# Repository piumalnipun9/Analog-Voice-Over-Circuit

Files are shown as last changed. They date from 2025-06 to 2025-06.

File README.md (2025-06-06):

# **Analog Voice-Over Circuit with Channel Prioritization**

This project demonstrates a fully analog implementation of a **Voice-Over Circuit** that effectively handles **two audio channels**, with automatic prioritization of the active channel.

## **Key Features**

- **Channel Prioritization**  
  Automatically prioritizes one channel when an input is detected, ensuring the most important channel is always heard.

- **Independent Volume Control**  
  Allows separate volume adjustments for both channels to tailor the audio output to specific needs.

- **Detection Threshold**  
  Adjustable detection threshold to ensure precise activation based on audio intensity.

- **Purely Analog Design**  
  Developed entirely using basic analog components and ICs, without digital processors, ensuring high-fidelity signal processing.

## **Functionality**

### 🔰 **Band-Pass Filter**  
The journey begins with a **band-pass filter**, which effectively improves the audio signal by reducing unwanted feedback and filtering out high-frequency noise. This step ensures that only the desired frequency range passes through for further processing.

### 🔰 **Pre-Amplifier**  
The filtered signal is then fed to a **pre-amplifier**, which boosts the signal to a level suitable for detection by the subsequent **peak detector circuit**. This ensures that the signal strength is sufficient for accurate analysis.

### 🔰 **Peak Detector Circuit**  
The **peak detector** captures the maximum amplitude of the audio signal, providing a stable DC output that is proportional to the peak amplitude. This step ensures that the highest level of the signal is preserved for accurate evaluation.

### 🔰 **Comparator Circuit**  
Next, the output from the peak detector is evaluated by a **comparator**. The comparator compares the peak value against a **predetermined threshold** and produces a high output when the signal surpasses this threshold. This decision determines whether audio from one channel or another should be activated.

### 🔰 **Control Signal for Switching**  
The **comparator's output** serves as a control signal to efficiently switch between the microphone input and the audio input. The priority channel is selected based on the detection of audio input.

### 🔰 **Main Amplifier**  
The final step involves the **main amplifier**, which amplifies the selected audio signal to a level that can be clearly heard through the **speaker**. The amplification ensures the output is loud and clear.

---

## **What We Learn From This Project**

- **Analog Signal Processing**  
  We gain hands-on experience in designing and implementing various analog circuits such as filters, amplifiers, and detectors. This emphasizes the importance of analog signal conditioning in real-world applications.

- **Audio Channel Management**  
  We learn how to handle multiple audio channels, manage input priorities, and ensure a seamless transition between them based on real-time detection, a valuable skill in audio systems and communication devices.

- **Threshold Detection and Signal Control**  
  This project teaches us how to use **thresholds** for activating or switching channels based on audio signals, a technique used in various applications like voice-activated systems and automatic switching systems.

- **Practical Circuit Integration**  
  Integrating multiple analog components—filters, amplifiers, detectors, comparators—into a cohesive working system gives us insight into how different analog devices can work together to form a complex functional unit.

---

## **Visuals of the Project**

<div style="display: flex; gap: 15px; justify-content: center; flex-wrap: wrap;">

  <!-- PCB -->
  <div style="text-align: center;">
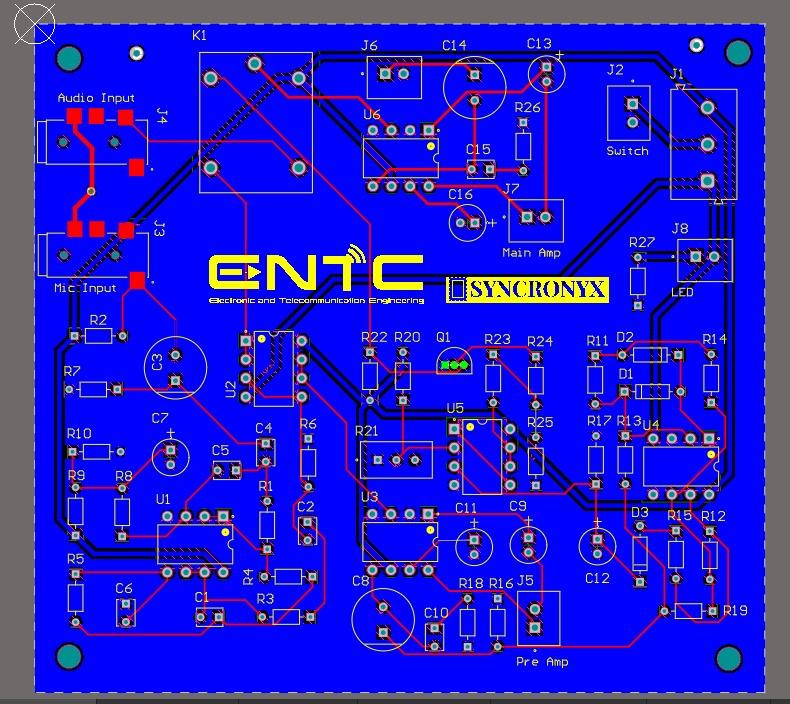
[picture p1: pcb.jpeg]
    
    <div>PCB Design</div>
  </div>

  <!-- Product Image 1 -->
  <div style="text-align: center;">
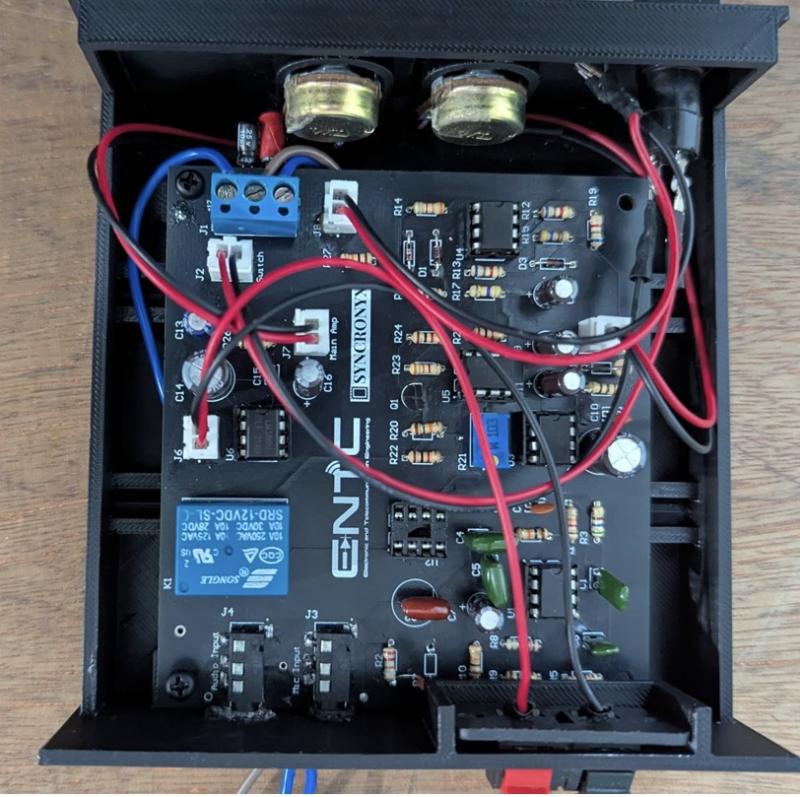
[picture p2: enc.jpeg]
    
    <div>Product Image (Front View)</div>
  </div>

  <!-- Product Image 2 + 3 combined -->
  <div style="text-align: center;">
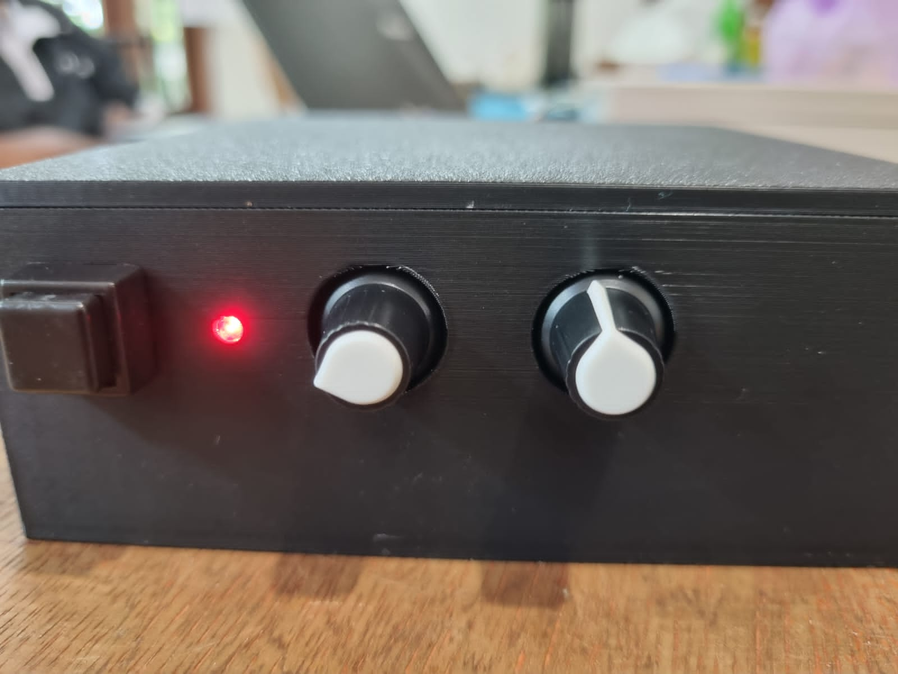
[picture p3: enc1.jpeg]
    
    
    <div>Product Images (Side & Rear Views)</div>
  </div>

</div>

<br/>

<!-- Signal Flow Diagram -->
<div style="text-align: center; margin-top: 30px;">
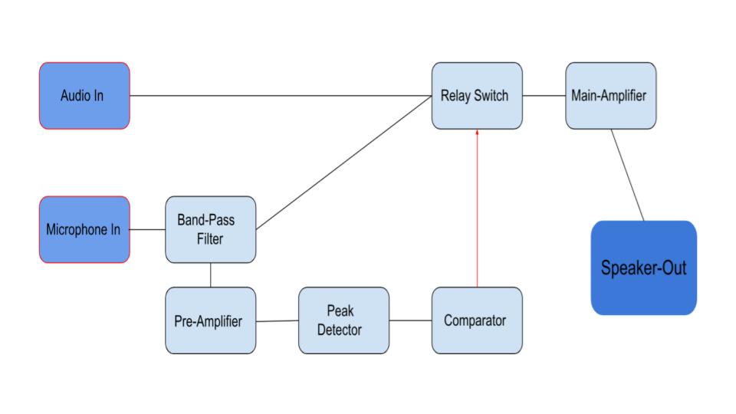
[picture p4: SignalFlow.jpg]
  
  <div>Signal Flow Diagram</div>
</div>

---
Video Demo
## **Components Used:**
- Band-pass filter
- Pre-amplifier IC
- Peak detector circuit
- Comparator IC
- Main amplifier IC
- Various passive components (resistors, capacitors)
## **Specific ICs Used:**
- LM386 for amplifier circuits
- NE5532 for other circuits
---

By completing this project, we develop a deeper understanding of analog systems, gain skills in circuit design and troubleshooting, and enhance our ability to create complex systems using only analog components.

Feel free to fork this repository and contribute to further improvements or modifications!

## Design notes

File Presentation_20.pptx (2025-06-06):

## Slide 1

Audio Voice Over Circuit

The audio voice-over circuit is designed to effortlessly alternate between two audio sources, typically a microphone input and an external audio input, based on user desire. It guarantees higher sound quality with minimum noise, distortion, and latency.

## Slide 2

Audio Voice Over Circuit

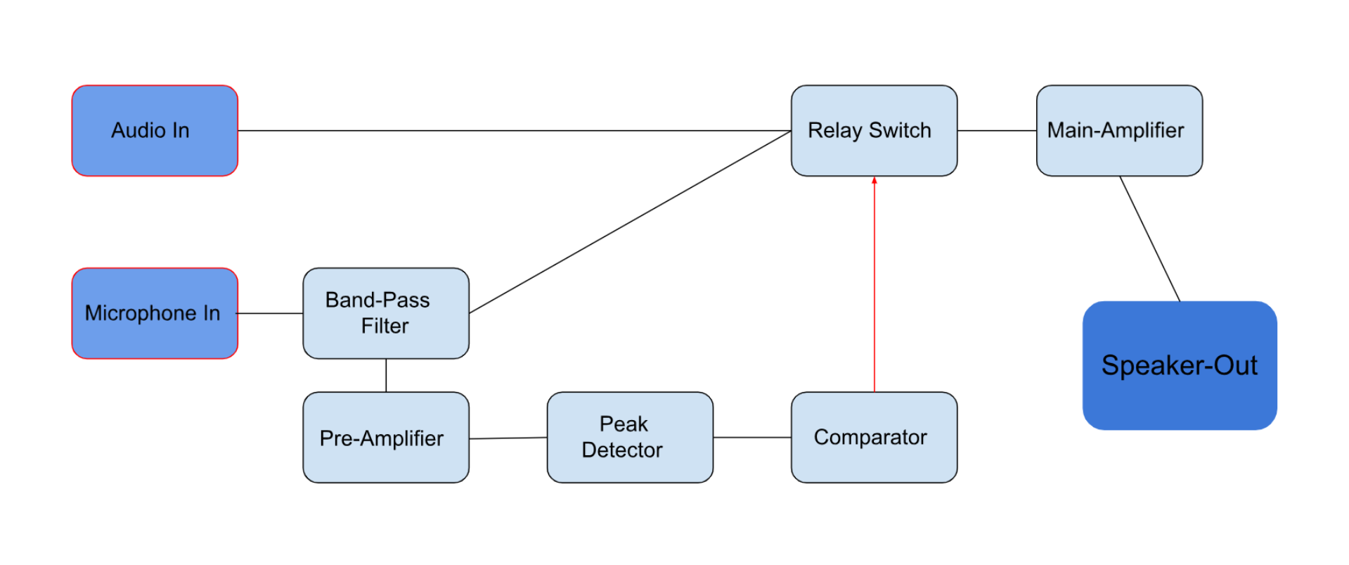
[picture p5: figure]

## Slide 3

Bandpass-Filter

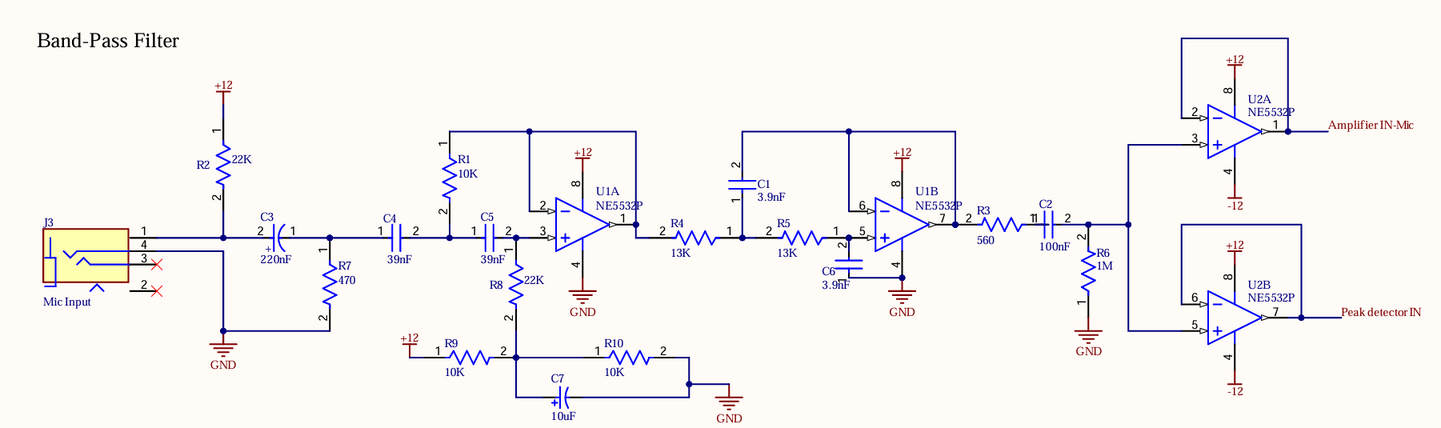
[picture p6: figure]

  - Used NE5532P IC containing two op-amps to build a bandpass filter.
  - Designed to reduce echo feedback from the microphone input.
  - Filter isolates the frequency range of 500-5000 Hz.
  - Ensures clear audio output by minimizing unwanted feedback and preserving signal quality.

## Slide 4

Pre-Amplifier

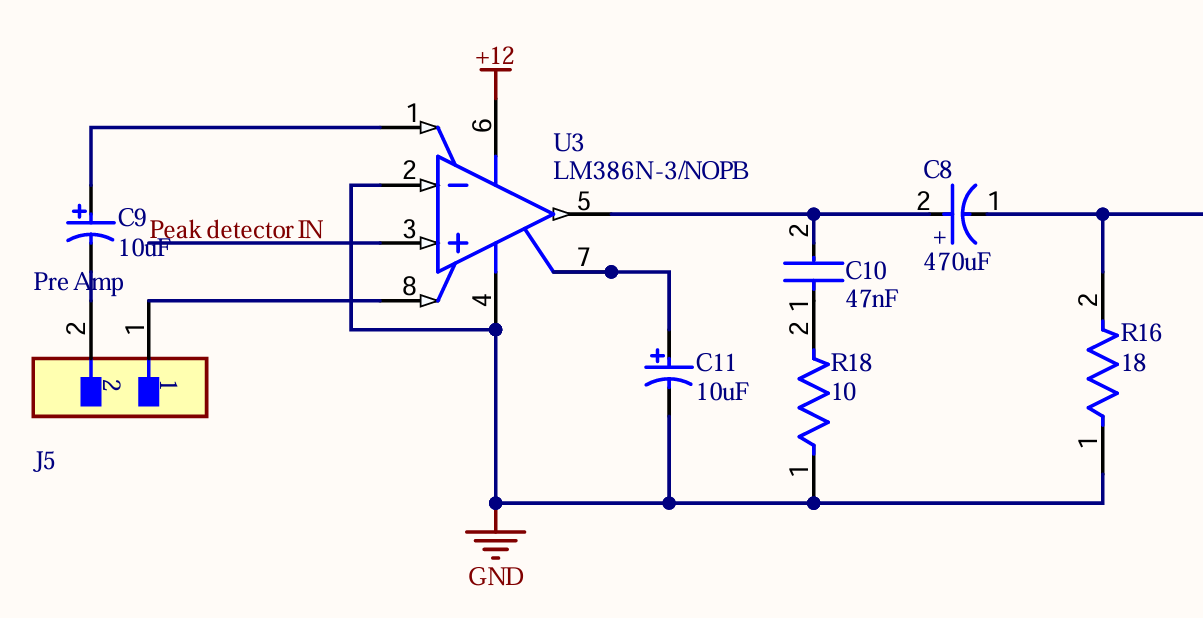
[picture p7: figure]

  - Band-Pass filter output drives through a pre-amplifier.

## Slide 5

Peak-Detector

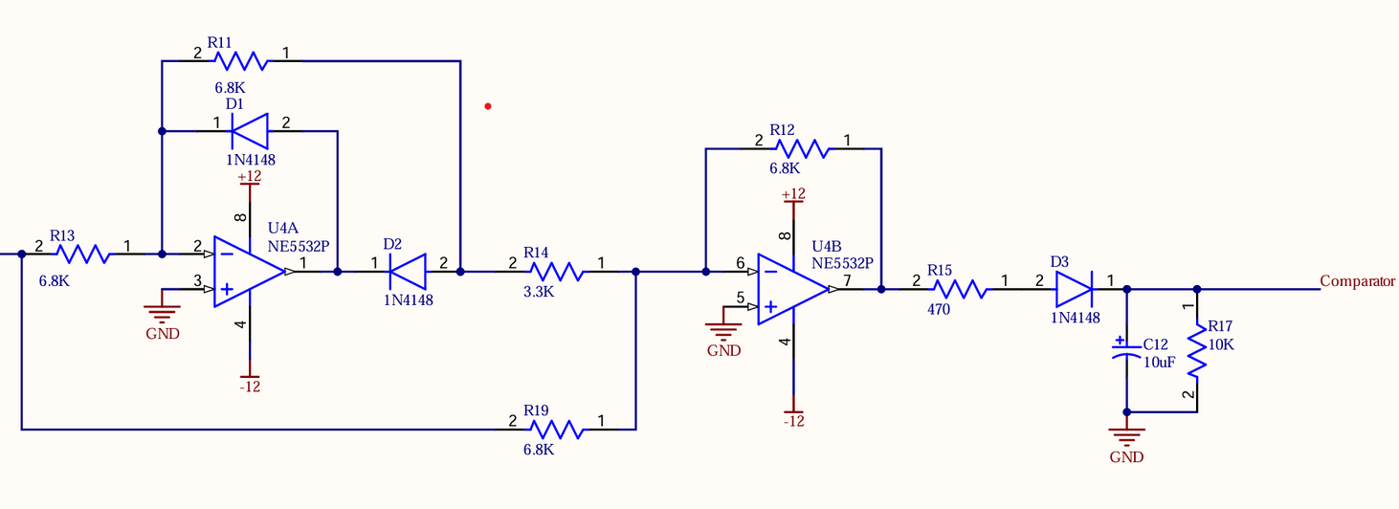
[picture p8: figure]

  - Utilized a NE5532P IC.
  - Circuit captures the peak amplitude of the input audio signal.
  - Provides a steady DC output proportional to the peak amplitude.
  - Output serves as the input to the comparator for threshold detection.

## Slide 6

Comparator

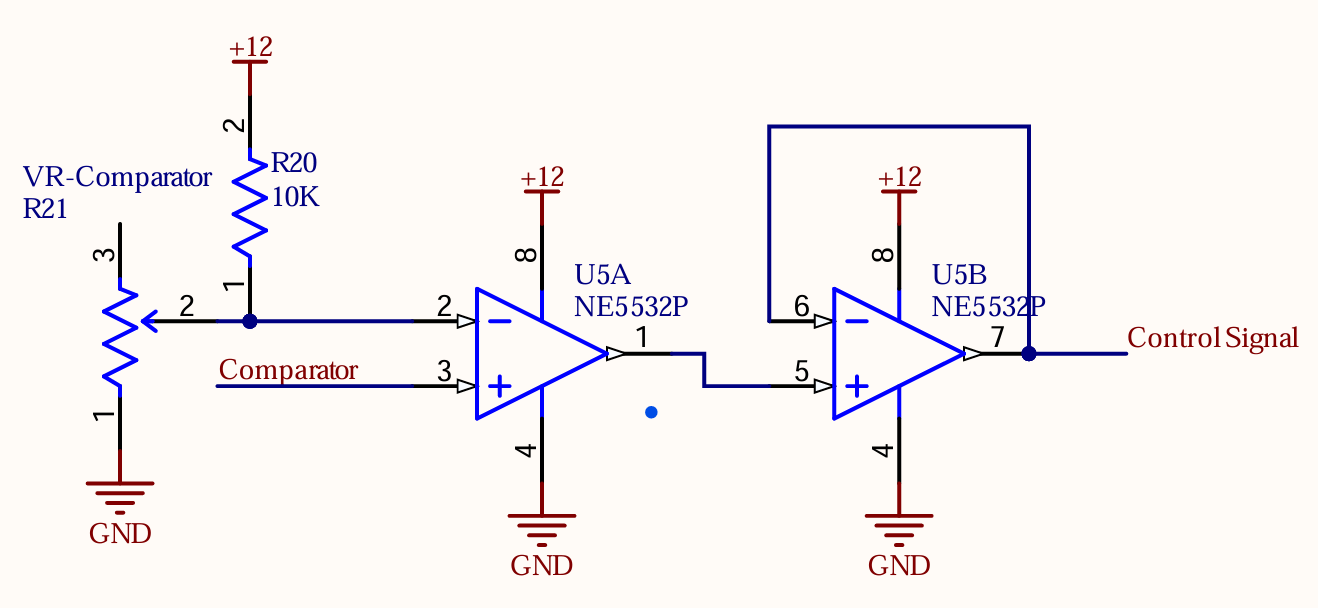
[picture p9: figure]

  - Used another NE5532P IC.
  - Comparator compares the peak detector’s output with a predefined threshold voltage.
  - Generates a high output when the peak signal exceeds the threshold.

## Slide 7

Switching-Circuit

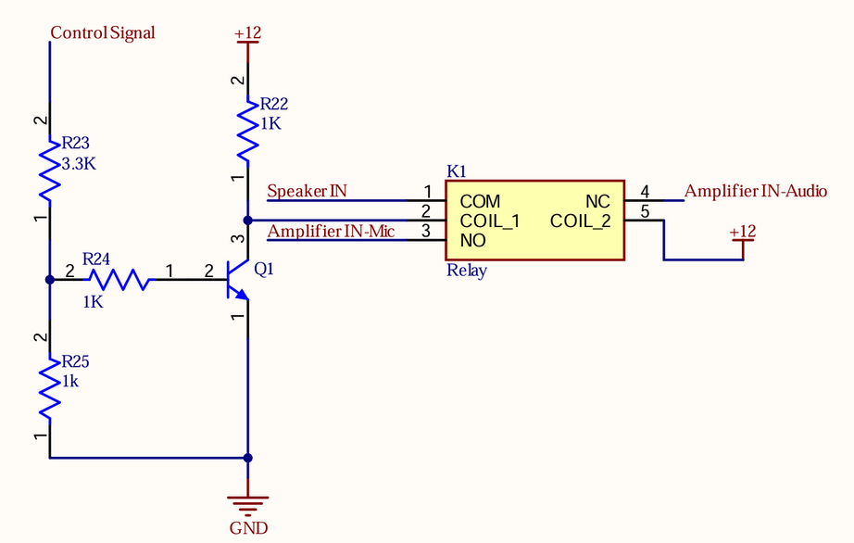
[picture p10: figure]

  - Employed a 2N3904 NPN transistor and a relay.
  - Comparator's output acts as the control signal for the circuit.
  - Transistor output drives the relay.
  - Ensures efficient signal routing between,
  1. microphone input
  2. audio input.

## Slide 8

Main-Amplifier

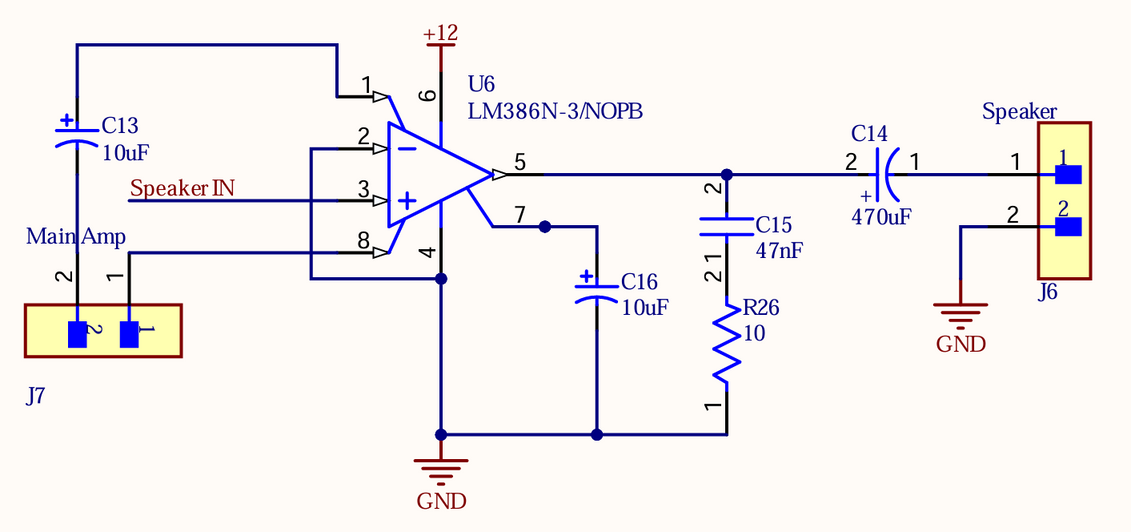
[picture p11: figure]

  - Used the LM386N IC to build an audio amplifier.
  - Designed to boost the signal strength for audio applications.
  - Provides sufficient gain and output power for clear sound.
  - Amplifies the input audio signal effectively.
  - Ensures compactness and energy efficiency in the overall design.

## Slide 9

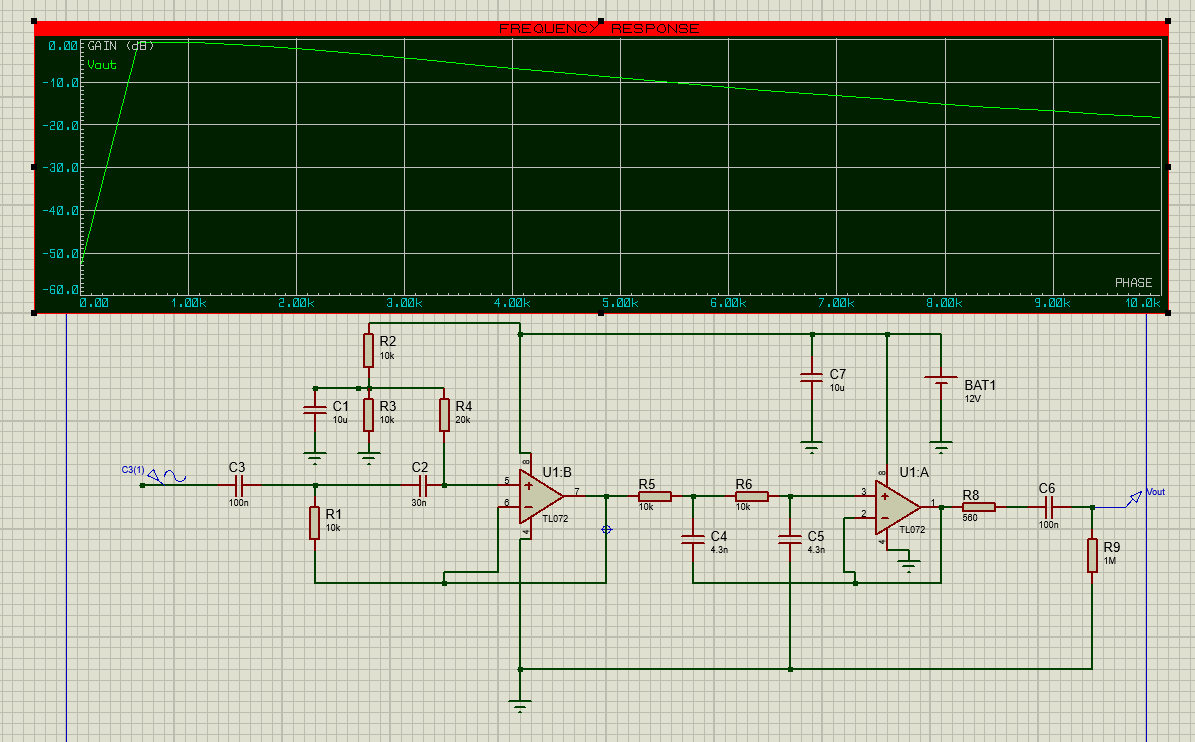
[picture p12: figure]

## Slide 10

PCB Design

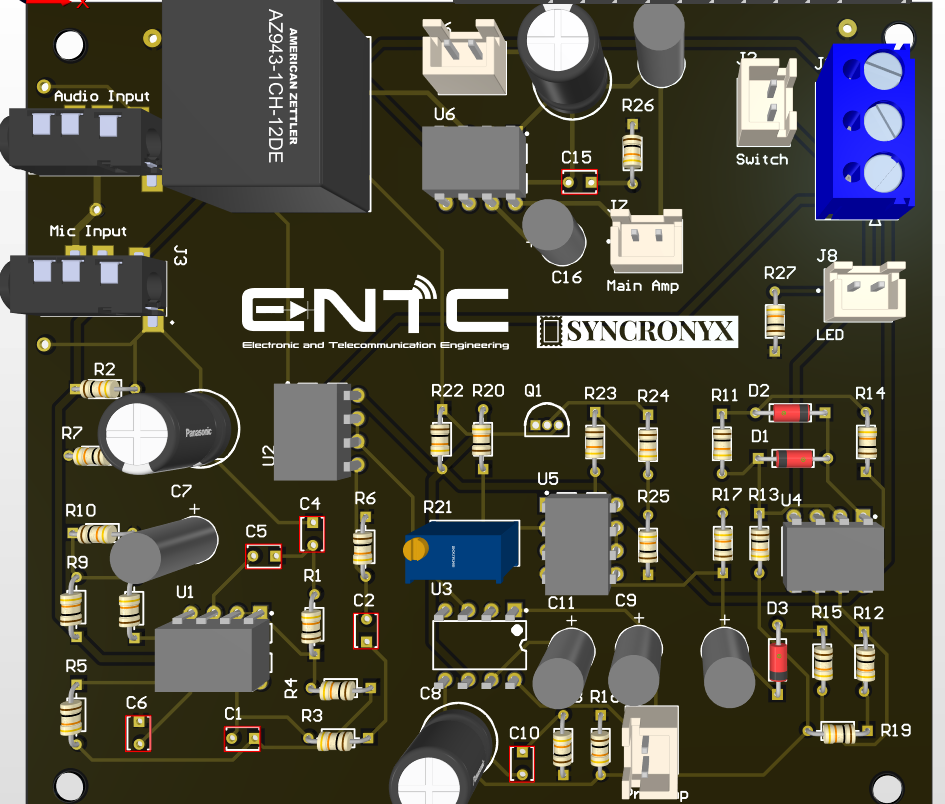
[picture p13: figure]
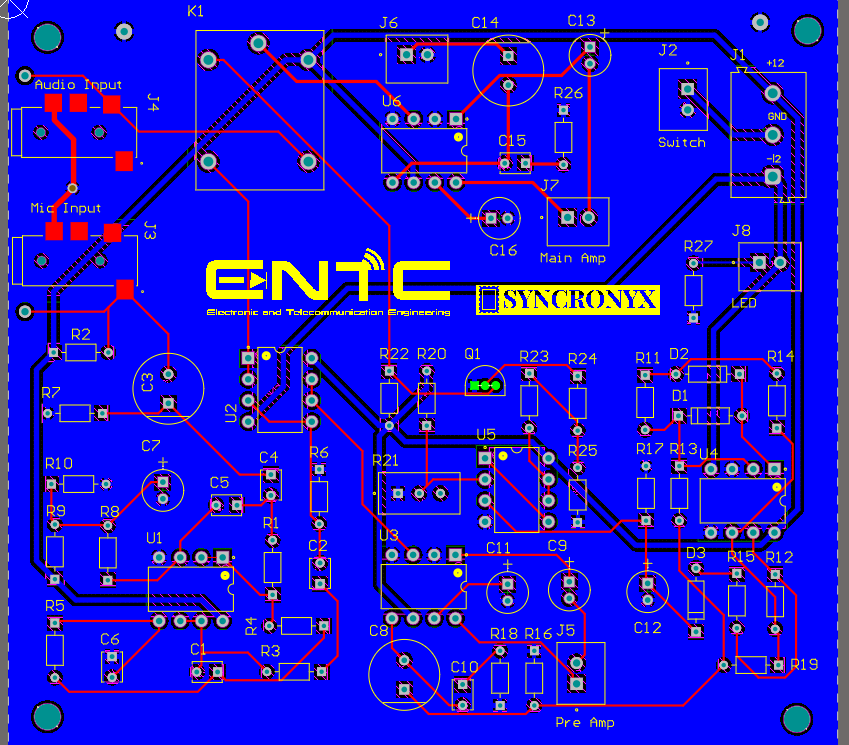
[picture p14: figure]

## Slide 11

Enclosure

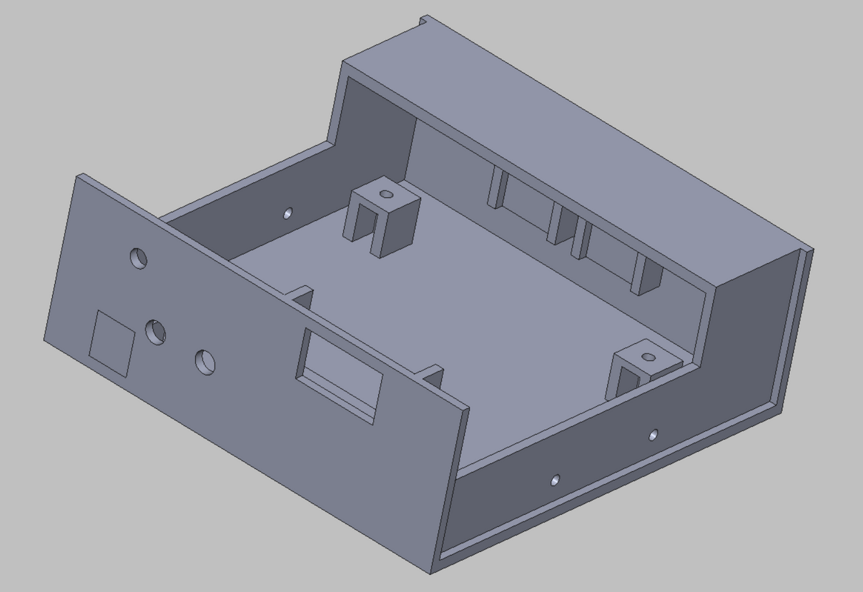
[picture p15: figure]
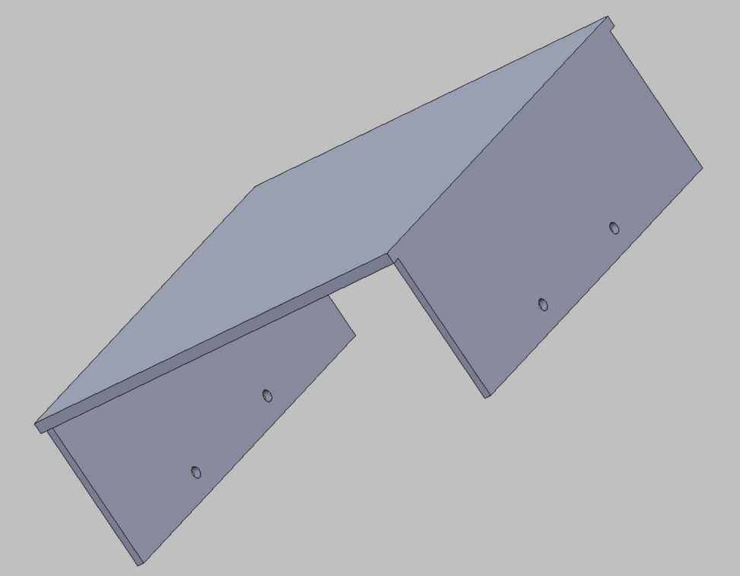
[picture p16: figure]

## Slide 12

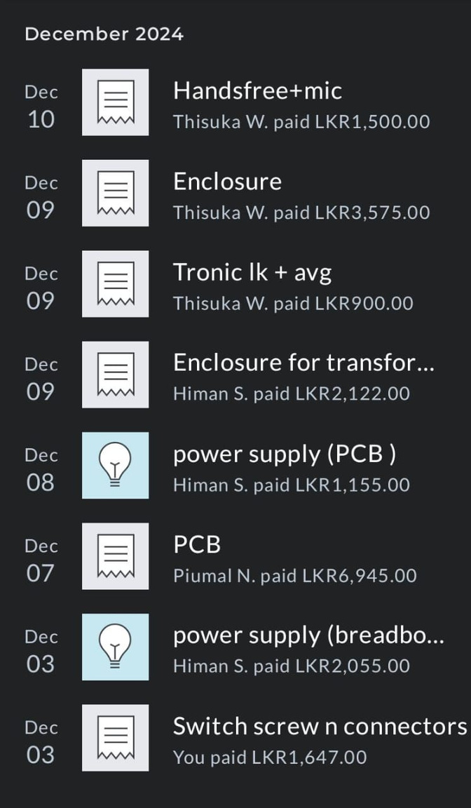
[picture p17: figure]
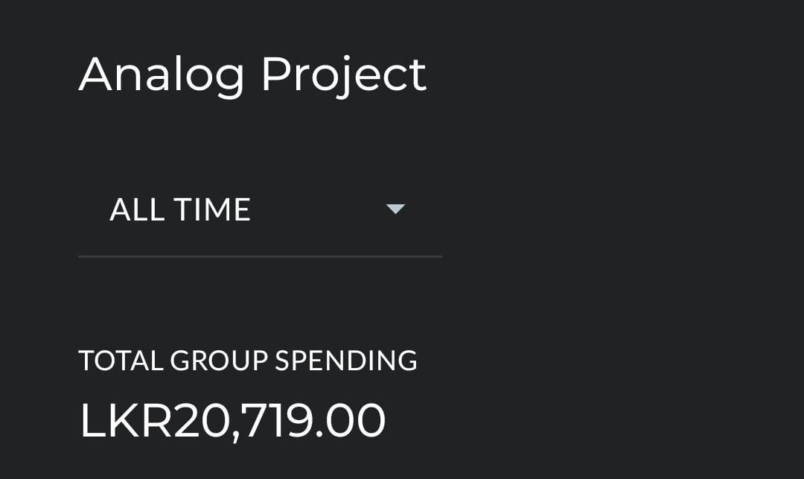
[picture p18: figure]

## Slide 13

Thank you!!!

Team Syncronix,

  - Bandara.I.W.T.N 220061H
  - Wijenayaka.M.B.T.I 220711D
  - Senaweera.S.A.H.D 220596C
  - Sanjeewa.P.M.G.P.N 220577U

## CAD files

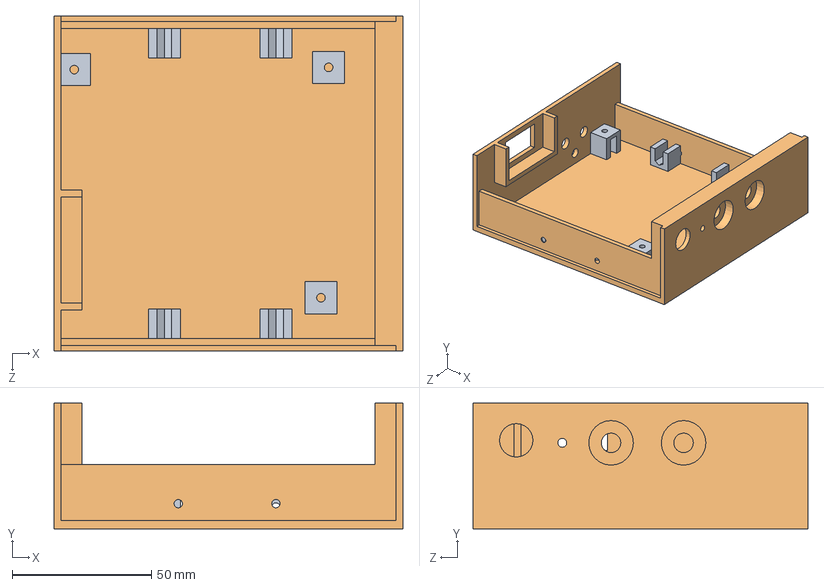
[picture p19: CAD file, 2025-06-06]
Enclosure_20/final2.SLDASM
125.0 x 45.0 x 120.1 mm
nuthole x 7

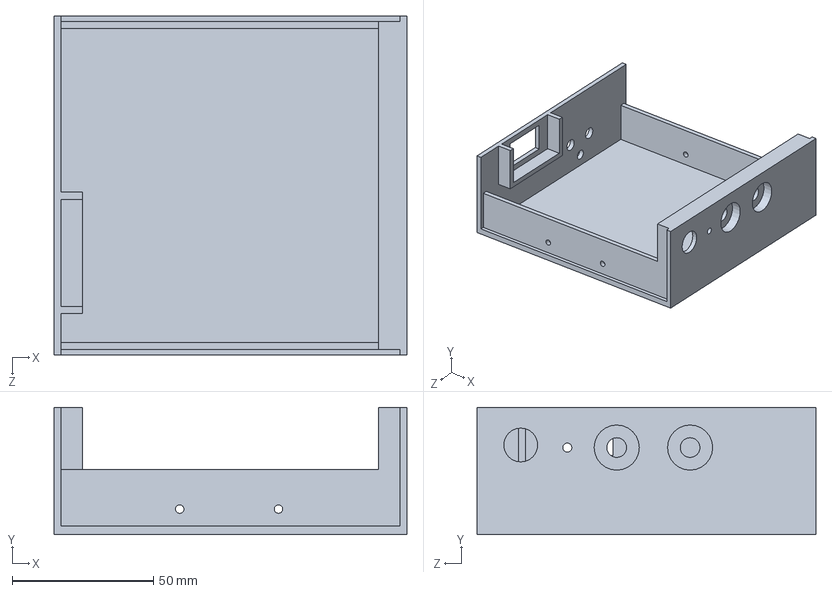
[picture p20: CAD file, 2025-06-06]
Enclosure_20/part2.SLDPRT
125.0 x 45.0 x 120.1 mm

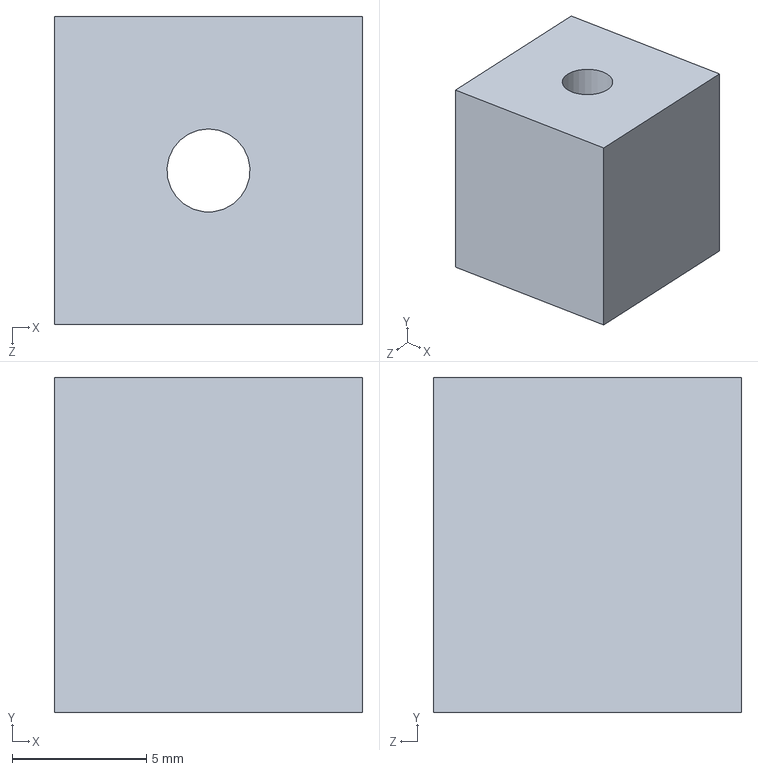
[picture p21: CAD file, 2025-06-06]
Enclosure_20/nuthole.SLDPRT
11.5 x 12.5 x 11.5 mm

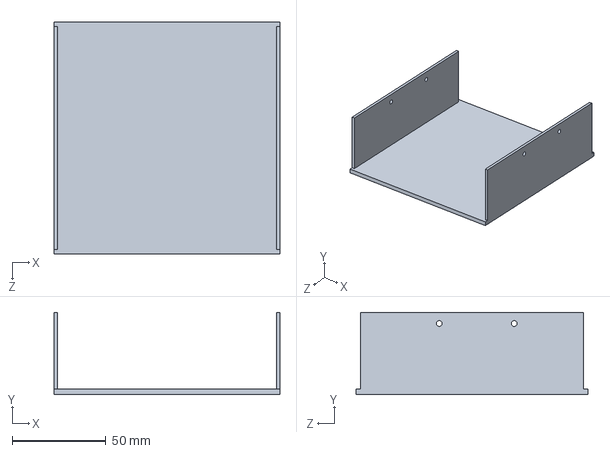
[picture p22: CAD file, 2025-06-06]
Enclosure_20/lid.SLDPRT
120.6 x 44.0 x 124.0 mm

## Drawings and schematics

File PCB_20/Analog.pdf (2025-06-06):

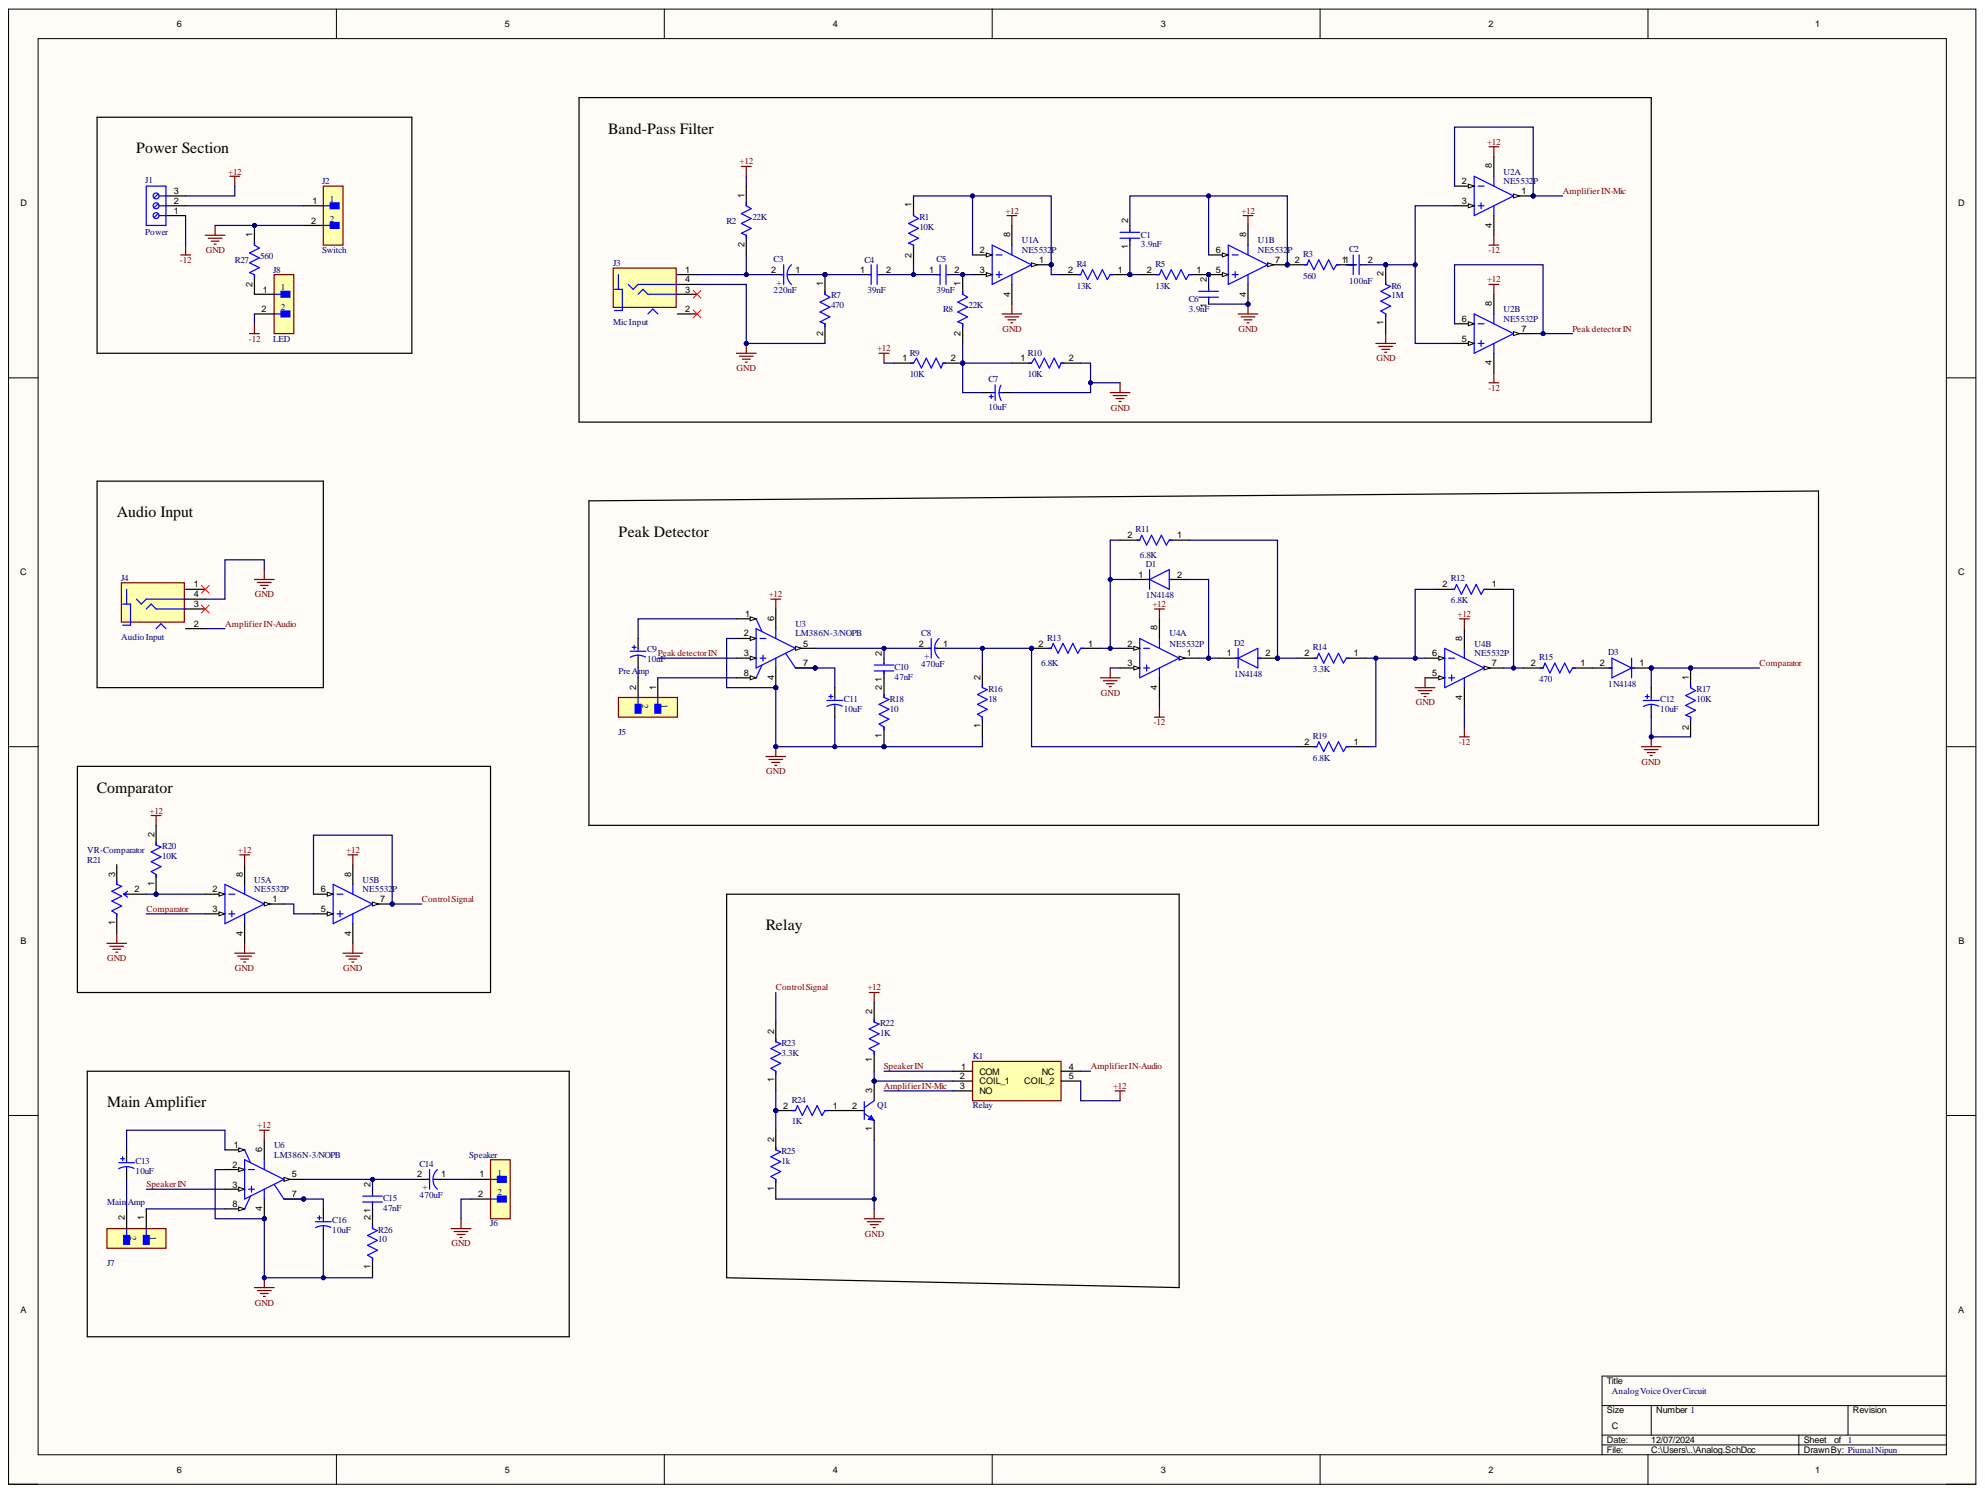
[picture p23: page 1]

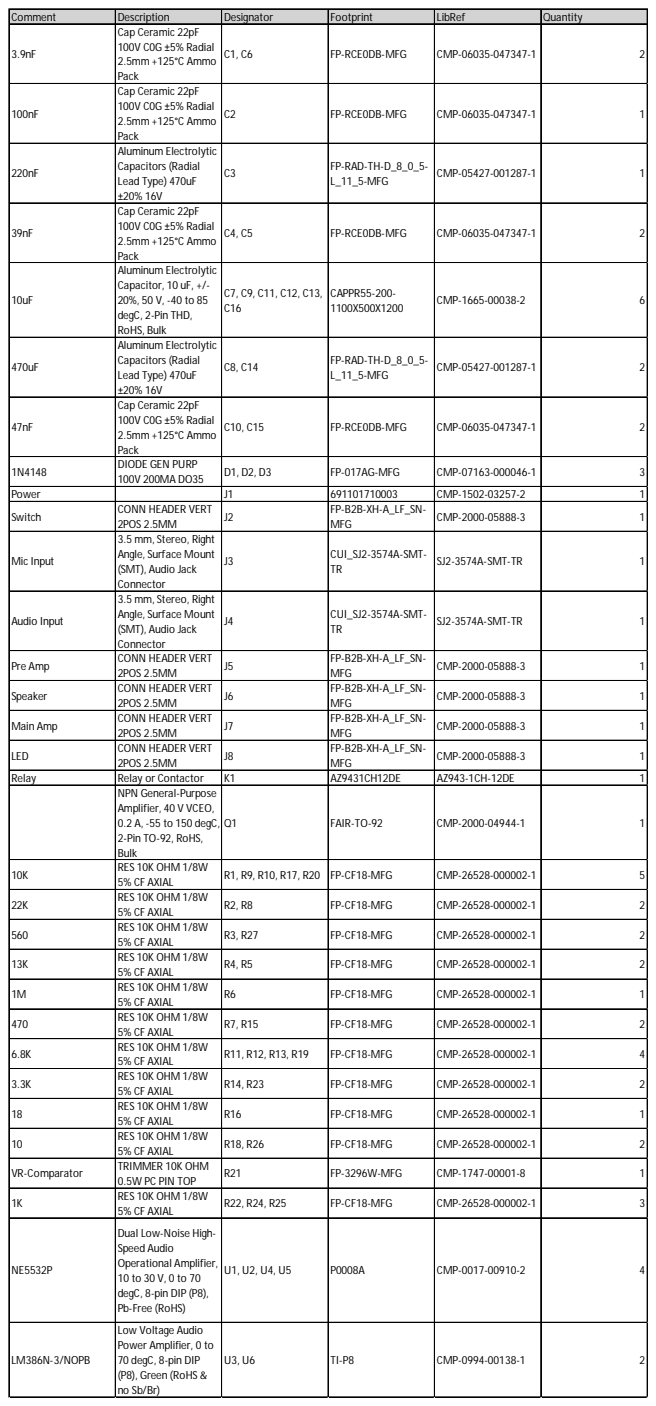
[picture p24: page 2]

Comment | Description | Designator | Footprint | LibRef | Quantity
3.9nF | Cap Ceramic 22pF 100V C0G ±5% Radial 2.5mm +125°C Ammo Pack | C1, C6 | FP-RCE0DB-MFG | CMP-06035-047347-1 | 2

100nF | Cap Ceramic 22pF 100V C0G ±5% Radial 2.5mm +125°C Ammo Pack | C2 | FP-RCE0DB-MFG | CMP-06035-047347-1 | 1

220nF | Aluminum Electrolytic Capacitors (Radial Lead Type) 470uF ±20% 16V | C3 | FP-RAD-TH-D_8_0_5-L_11_5-MFG | CMP-05427-001287-1 | 1

39nF | Cap Ceramic 22pF 100V C0G ±5% Radial 2.5mm +125°C Ammo Pack | C4, C5 | FP-RCE0DB-MFG | CMP-06035-047347-1 | 2

10uF | Aluminum Electrolytic Capacitor, 10 uF, +/-20%, 50 V, -40 to 85 degC, 2-Pin THD, RoHS, Bulk | C7, C9, C11, C12, C13, C16 | CAPPR55-200-1100X500X1200 | CMP-1665-00038-2 | 6

470uF | Aluminum Electrolytic Capacitors (Radial Lead Type) 470uF ±20% 16V | C8, C14 | FP-RAD-TH-D_8_0_5-L_11_5-MFG | CMP-05427-001287-1 | 2

47nF | Cap Ceramic 22pF 100V C0G ±5% Radial 2.5mm +125°C Ammo Pack | C10, C15 | FP-RCE0DB-MFG | CMP-06035-047347-1 | 2

1N4148 | DIODE GEN PURP 100V 200MA DO35 | D1, D2, D3 | FP-017AG-MFG | CMP-07163-000046-1 | 3

Power | | J1 | 691101710003 | CMP-1502-03257-2 | 1
Switch | CONN HEADER VERT 2POS 2.5MM | J2 | FP-B2B-XH-A_LF_SN-MFG | CMP-2000-05888-3 | 1

Mic Input | 3.5 mm, Stereo, Right Angle, Surface Mount (SMT), Audio Jack Connector | J3 | CUI_SJ2-3574A-SMT-TR | SJ2-3574A-SMT-TR | 1

Audio Input | 3.5 mm, Stereo, Right Angle, Surface Mount (SMT), Audio Jack Connector | J4 | CUI_SJ2-3574A-SMT-TR | SJ2-3574A-SMT-TR | 1

Pre Amp | CONN HEADER VERT 2POS 2.5MM | J5 | FP-B2B-XH-A_LF_SN-MFG | CMP-2000-05888-3 | 1

Speaker | CONN HEADER VERT 2POS 2.5MM | J6 | FP-B2B-XH-A_LF_SN-MFG | CMP-2000-05888-3 | 1

Main Amp | CONN HEADER VERT 2POS 2.5MM | J7 | FP-B2B-XH-A_LF_SN-MFG | CMP-2000-05888-3 | 1

LED | CONN HEADER VERT 2POS 2.5MM | J8 | FP-B2B-XH-A_LF_SN-MFG | CMP-2000-05888-3 | 1

Relay | Relay or Contactor | K1 | AZ9431CH12DE | AZ943-1CH-12DE | 1

NPN General-Purpose Amplifier, 40 V VCEO, 0.2 A, -55 to 150 degC, 2-Pin TO-92, RoHS, Bulk | Q1 | FAIR-TO-92 | CMP-2000-04944-1 | 1

10K | RES 10K OHM 1/8W 5% CF AXIAL | R1, R9, R10, R17, R20 | FP-CF18-MFG | CMP-26528-000002-1 | 5

22K | RES 10K OHM 1/8W 5% CF AXIAL | R2, R8 | FP-CF18-MFG | CMP-26528-000002-1 | 2

560 | RES 10K OHM 1/8W 5% CF AXIAL | R3, R27 | FP-CF18-MFG | CMP-26528-000002-1 | 2

13K | RES 10K OHM 1/8W 5% CF AXIAL | R4, R5 | FP-CF18-MFG | CMP-26528-000002-1 | 2

1M | RES 10K OHM 1/8W 5% CF AXIAL | R6 | FP-CF18-MFG | CMP-26528-000002-1 | 1

470 | RES 10K OHM 1/8W 5% CF AXIAL | R7, R15 | FP-CF18-MFG | CMP-26528-000002-1 | 2

6.8K | RES 10K OHM 1/8W 5% CF AXIAL | R11, R12, R13, R19 | FP-CF18-MFG | CMP-26528-000002-1 | 4

3.3K | RES 10K OHM 1/8W 5% CF AXIAL | R14, R23 | FP-CF18-MFG | CMP-26528-000002-1 | 2

18 | RES 10K OHM 1/8W 5% CF AXIAL | R16 | FP-CF18-MFG | CMP-26528-000002-1 | 1

10 | RES 10K OHM 1/8W 5% CF AXIAL | R18, R26 | FP-CF18-MFG | CMP-26528-000002-1 | 2

VR-Comparator | TRIMMER 10K OHM 0.5W PC PIN TOP | R21 | FP-3296W-MFG | CMP-1747-00001-8 | 1

1K | RES 10K OHM 1/8W 5% CF AXIAL | R22, R24, R25 | FP-CF18-MFG | CMP-26528-000002-1 | 3

NE5532P | Dual Low-Noise High-Speed Audio Operational Amplifier, 10 to 30 V, 0 to 70 degC, 8-pin DIP (P8), Pb-Free (RoHS) | U1, U2, U4, U5 | P0008A | CMP-0017-00910-2 | 4

LM386N-3/NOPB | Low Voltage Audio Power Amplifier, 0 to 70 degC, 8-pin DIP (P8), Green (RoHS & no Sb/Br) | U3, U6 | TI-P8 | CMP-0994-00138-1 | 2
